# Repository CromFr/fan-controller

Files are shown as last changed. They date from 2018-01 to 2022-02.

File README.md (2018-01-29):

# Arduino fan controller

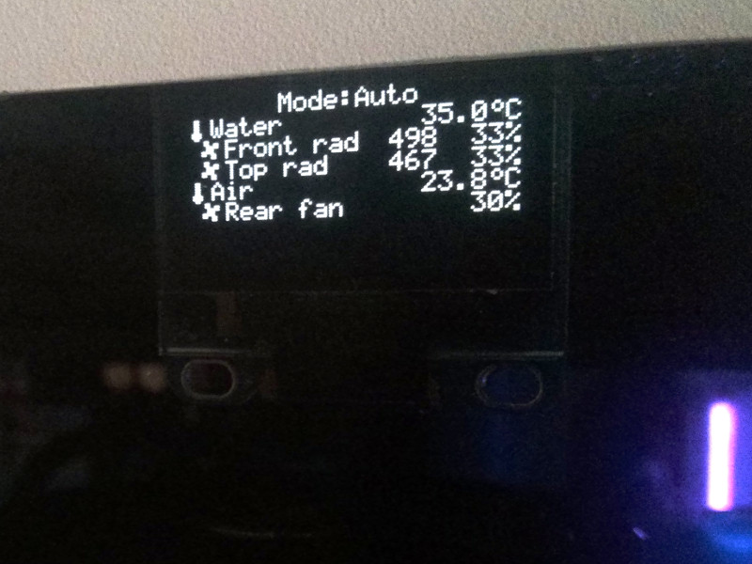
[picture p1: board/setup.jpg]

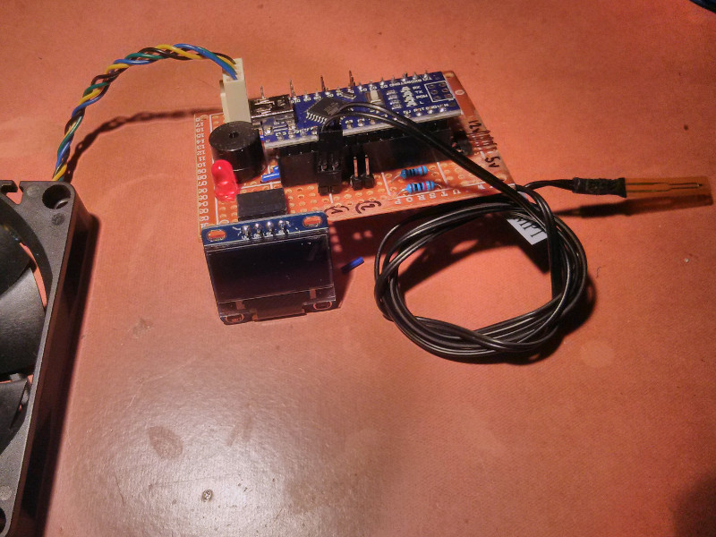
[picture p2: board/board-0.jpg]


# Features
- Control fan speeds by using the following modes:
    + _Auto_: Use temperature->speed curves for each fan
    + _Low_: All fans sets to their lowest value on the curve (that is not 0)
    + _High_: All fans to their highest value on the curve (that is not 100)
    + _Full_: All fans to 100%
- SSD1306 Display:
    + Fan speed control mode
    + Sensor temperature
    + Fan speeds percent (with RPM if tachometer is available)
- Buzzer:
    - When there is no display: beep to transmit control mode and temperature
    - Beep when temperature is critical
- Warning led: Blink when in low speed mode (as temperature may rise)
- Button:
    + Short button press
        * Send control mode, temperatures and fan speeds to serial output
        * Beep first temperature (mix of morse and roman numbers)
            - `.`: 1, `..`: 2, `...`: 3, `.-`: 4, `-`: 5, `-.`: 6, `-..`: 7, `-...`: 8, `.--`: 9, `--`: 0
    + Long button press: Switch fan control modes
        * Auto (beep `.-`, morse code for A)
        * Low (beep `.-..`, morse code for L)
        * High (beep `....`, morse code for H)
        * Full (beep `..-.`, morse code for F)

# Setup

- Install dependencies
	+ On GNU/Linux platforms, execute `./arduino-install-libs.sh`
	+ On Windows platform, using the Arduino Library manager, install the following libraries:
		* `ssd1306` by Alexey Dynda
- Edit `config.cpp` to configure the different settings:
    + Pinout
    + Sensor list: pin
    + Fan list: pin, speed curve, associated sensor
    + SSD1306 display connection
    + ...

# Board

Perfboard design & photos in [board/](board/)

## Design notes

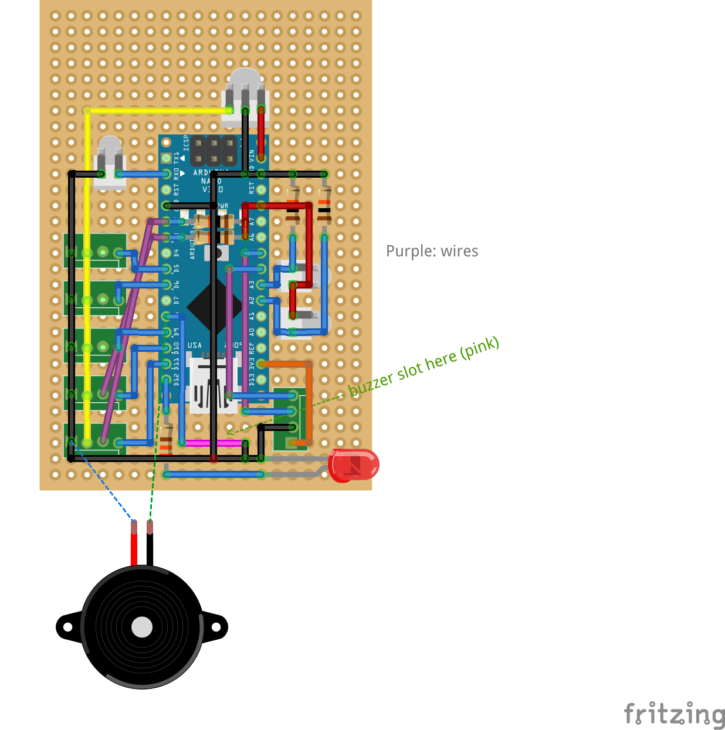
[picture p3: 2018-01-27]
board/breadboard.png

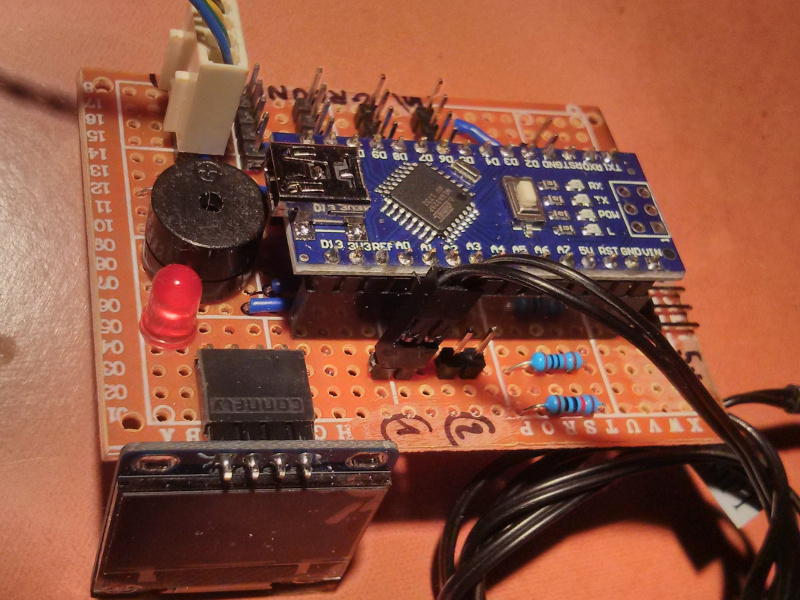
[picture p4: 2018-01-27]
board/board-1.jpg

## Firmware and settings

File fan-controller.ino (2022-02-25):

#include <Arduino.h>
#include "display.h"
#include "buzzer.h"

#include "config.h"


Sensor* sensors;
Fan* fans;
Buzzer buzzer;
Display display;
bool kickStart;


void setup() {
	Serial.begin(9600);

	pinMode(ledPin, OUTPUT);
	analogWrite(ledPin, 0);

	pinMode(buttonPin, INPUT_PULLUP);

	buzzer = Buzzer(buzzerPin);

	sensors = new Sensor[sensorsLength];
	for(uint8_t i = 0 ; i < sensorsLength ; i++)
		sensors[i] = Sensor(&sensorDefs[i]);

	fans = new Fan[fansLength];
	for(uint8_t i = 0 ; i < fansLength ; i++){
		fans[i] = Fan(&fanDefs[i], &sensors[fanDefs[i].sensorIndex]);
	}

	if(hasDisplay){
		display = Display(sensors, sensorsLength, fans, fansLength);
	}

	kickStart = true;
}

void loop() {
	static uint8_t counter = 0;
	static Mode mode = Mode::Auto;

	if(kickStart && millis() > 500)
		kickStart = false;

	// average temp over a second
	for(uint8_t i = 0 ; i < sensorsLength ; i++){
		sensors[i].measureTemp();
	}

	// Handle button actions
	if(digitalRead(buttonPin) == 0){
		auto startPress = millis();
		bool longPress = false;

		while(digitalRead(buttonPin) == 0){
			auto duration = millis() - startPress;
			if(duration > 300){
				longPress = true;
				break;
			}
		}

		if(longPress){
			// Change mode
			mode = (Mode)(((int)mode + 1) % 4);
			if(buzzer.isActive()){
				if(hasDisplay)
					buzzer.beep(".");
				else{
					switch(mode){
						case Mode::Auto: buzzer.beep(".-");   break;
						case Mode::Low:  buzzer.beep(".-.."); break;
						case Mode::High: buzzer.beep("...."); break;
						case Mode::Full: buzzer.beep("..-."); break;
						default: buzzer.beep("----------");
					}
				}
			}

			// Will force fan speed set immediately with current temp values
			counter = 0;

			//Switch off warning led
			digitalWrite(ledPin, false);

			Serial.print("Mode;");
			Serial.println(modeToStr(mode));
		}
		else{
			// Display temps & speeds
			Serial.print("Mode;");
			Serial.println(modeToStr(mode));

			for(uint8_t i = 0 ; i < sensorsLength ; i++){
				auto& sensor = sensors[i];
				Serial.print("Sensor;");
				Serial.print(sensor.def->name);
				Serial.print(";");
				Serial.print(sensor.smoothedTemp());
				Serial.print("°C");
				Serial.println("");
			}

			for(uint8_t i = 0 ; i < fansLength ; i++){
				auto& fan = fans[i];
				Serial.print("Fan;");
				Serial.print(fan.def->name);
				Serial.print(";");
				Serial.print(fan.currentSpeed());
				Serial.print("%");
				if(fan.hasTacho()){
					Serial.print(";");
					Serial.print(fan.getRPM());
					Serial.print("RPM");
				}
				Serial.println("");
			}

			// Beep first temp
			if(buzzer.isActive())
				buzzer.beepNumber(sensors[0].smoothedTemp());
		}

		// Wait release
		while(digitalRead(buttonPin) == 0){}
	}

	// Set fan speeds
	if(counter == 0){
		// Fan control
		for(uint8_t i = 0 ; i < fansLength ; i++){
			if(kickStart && fans[i].def->kickStart)
				fans[i].setSpeed(100);
			else
				fans[i].setModeSpeed(mode);
		}

		if(hasDisplay){
			// Update display
			display.update(mode);
		}

		bool ledBlink = false;
		bool ledFlash = false;
		bool buzzerLongBeep = false;
		bool buzzerShortBeep = false;


		// Sensor temp warning & malfunction detection
		for(uint8_t i = 0 ; i < sensorsLength ; i++){
			auto temp = sensors[i].smoothedTemp();
			if(temp < -273.0 || temp > 273.0){
				// -273.1 means the sensor is disconnected
				// +273.1 means the sensor is short circuited
				buzzerShortBeep = true;
			}

			auto& maxTemp = sensors[i].def->maxTemp;
			if(!isnan(maxTemp) && temp >= maxTemp){
				buzzerLongBeep = true;
			}
		}

		if(mode == Mode::Low)
			ledBlink = true;

		static bool stateSwitch = false;
		stateSwitch = !stateSwitch;

		// Led
		if(ledBlink)
			digitalWrite(ledPin, stateSwitch);
		else if(ledFlash){
			digitalWrite(ledPin, 1);
			delay(50);
			digitalWrite(ledPin, 0);
		}
		else{
			digitalWrite(ledPin, 0);
		}

		// Buzzer
		if(buzzerLongBeep){
			// Buzz if dangerous temp
			if(buzzer.isActive()) buzzer.set(stateSwitch);
			else buzzer.set(false);
		}
		else if(buzzerShortBeep){
			buzzer.beep(".");
		}


		// Tachometer counters reset
		for(uint8_t i = 0 ; i < fansLength ; i++){
			if(fans[i].hasTacho()){
				fans[i].resetTacho();
			}
		}
	}

	counter = (counter + 1 ) % 20;
	if(counter == 0){
		for(uint8_t i = 0 ; i < sensorsLength ; i++){
			sensors[i].resetTemp();
		}
	}
	delay(50);
}

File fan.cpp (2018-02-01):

#include "fan.h"


const char* modeToStr(Mode mode){
	switch(mode){
		case Mode::Auto: return "Auto";
		case Mode::Low:  return "Low";
		case Mode::High: return "High";
		case Mode::Full: return "Full";
	}
	return "UNKNOWN";
}

// This can handle 2 tachometers
static volatile uint32_t tachoCounters[TACHOMETER_MAX] = {0};
static void (*onTachoCbs[TACHOMETER_MAX])() = {
	[](){ tachoCounters[0]++; },
	[](){ tachoCounters[1]++; },
};
static uint8_t onTachoCbsCnt = 0;


Fan::Fan(const FanDef* _def, const Sensor* sensor): def(_def), sensor(sensor) {

	// Determinate min & max speed
	minSpeed = 100;
	maxSpeed = 0;
	for(int j = 0; j < def->speedCurveLength; j++){
		auto& speed = def->speedCurve[j].speed;

		if(speed > 0 && speed < minSpeed)
			minSpeed = speed;
		if(speed < 100 && speed > maxSpeed)
			maxSpeed = speed;
	}

	// Configure PWM
	static bool configured25KHz = false;
	if((def->pin == 9 || def->pin == 10) && !configured25KHz){
		// Setup 25KHz PWM on pin 9 and 10 to match the intel fan specs
		// Configure Timer 1 for PWM @ 25 kHz.
		TCCR1A = 0;           // undo the configuration done by...
		TCCR1B = 0;           // ...the Arduino core library
		TCNT1  = 0;           // reset timer
		TCCR1A = _BV(COM1A1)  // non-inverted PWM on ch. A
		       | _BV(COM1B1)  // same on ch; B
		       | _BV(WGM11);  // mode 10: ph. correct PWM, TOP = ICR1
		TCCR1B = _BV(WGM13)   // ditto
		       | _BV(CS10);   // prescaler = 1
		ICR1   = 320;         // TOP = 320

		configured25KHz = true;
	}

	// Configure pins
	pinMode(def->pin, OUTPUT);

	// Configure tachometer if any
	if(def->tachoPin != (uint8_t)-1){
		if(onTachoCbsCnt >= TACHOMETER_MAX){
			Serial.println("Warning: cannot handle so many tachometers. Please edit TACHOMETER_MAX in " __FILE__);
		}
		else {
			tachoCounter = &tachoCounters[onTachoCbsCnt];

			pinMode(def->tachoPin, INPUT_PULLUP);
			attachInterrupt(digitalPinToInterrupt(def->tachoPin), onTachoCbs[onTachoCbsCnt], RISING);
			onTachoCbsCnt++;
		}
		resetTacho();
	}
}

void Fan::setSpeed(uint8_t speed){
	this->speed = speed;

	switch (def->pin) {
		case 9:
			OCR1A = speed / 100.0 * 320;
			break;
		case 10:
			OCR1B = speed / 100.0 * 320;
			break;
		default:
			analogWrite(def->pin, speed / 100.0 * 255);
			break;
	}
}


void Fan::setModeSpeed(Mode mode){
	switch(mode){
		case Mode::Auto:
			setSpeed(calcSpeed(sensor->smoothedTemp()));
			break;
		case Mode::Low:
			setSpeed(minSpeed);
			break;
		case Mode::High:
			setSpeed(maxSpeed);
			break;
		case Mode::Full:
			setSpeed(100);
			break;
	}
}

uint16_t Fan::getRPM() const {
	//   2 pulse per revolution
	return (*tachoCounter / 2ul) * (60.0  / ((millis() - tachoTimer) / 1000.0));
}


uint8_t Fan::calcSpeed(double temp) const {
	SpeedCurvePoint* start = nullptr;
	SpeedCurvePoint* end = nullptr;

	for(int i = 0 ; i < def->speedCurveLength ; i++){

		if(def->speedCurve[i].temp > temp){
			end = &def->speedCurve[i];
			break;
		}
		start = &def->speedCurve[i];
	}

	if(start == nullptr){
		return end->speed;
	}
	if(end == nullptr){
		return start->speed;
	}

	//interpolate
	double pitch = (double)(end->speed - start->speed) / (double)(end->temp - start->temp);
	double offset = start->speed - pitch * start->temp;
	return pitch * temp + offset;
}

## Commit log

2018-01-13 Fix weird Mode casting issue
    [fan_controler.ino]
2018-01-18 Add 25KHz PWM config
2018-01-21 Tacho display & fan cleaning
2018-01-21 Improved sensors config
2018-01-25 Beep mode only if has no display & fix arduino project file name
    [fan-controller.ino]
2018-01-25 Temperature warning
2018-01-25 Final pin adjustments
2018-01-27 Board design
    [sketch.fzz]
2018-02-01 Short beep if temp sensor is disconnected
    [fan-controller.ino]
2018-02-01 Fix: Led state reset
    [fan-controller.ino]
2018-02-01 Fix: Added tachometer serial output
    [fan.cpp]
2022-02-25 Kickstart feature for starting fans at 100% power
